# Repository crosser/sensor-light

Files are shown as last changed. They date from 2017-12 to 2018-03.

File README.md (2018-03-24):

## LED strip light controller ##

The project is to drive night lighting of a staircase using PIR
motion sensors (two: for the top and bottom of the staircase).
Ambient light sensor to only turn the LED chain when it is dark.
Driven by MSP430 MCU, light power controlled via PWM + MOSFET.



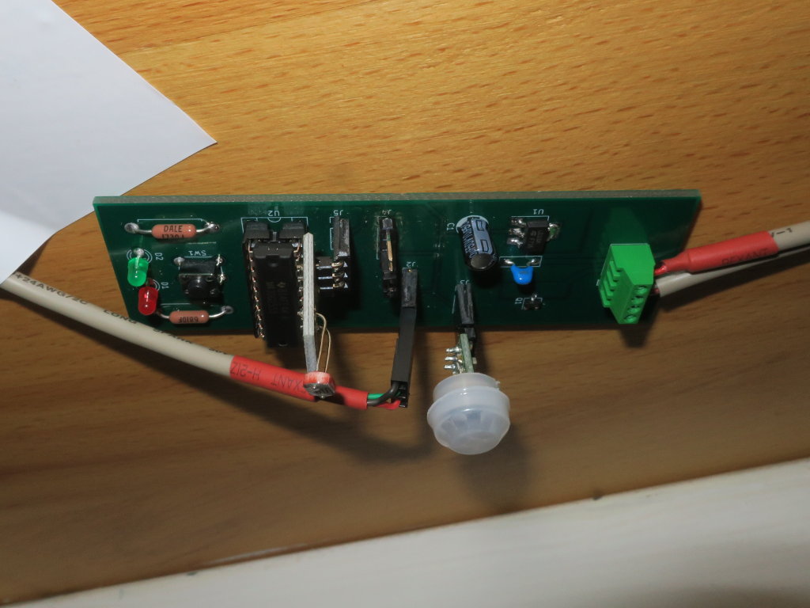
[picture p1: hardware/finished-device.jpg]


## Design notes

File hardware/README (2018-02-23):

Using this suggestion from electronics stackexchange:

https://electronics.stackexchange.com/questions/67775/driving-led-strip-from-microcontroller

MOSFET datasheet:

https://www.infineon.com/dgdl/irlml2502.pdf?fileId=5546d462533600a401535667f44d2602

MCU Power supply datasheet:

https://www.sparkfun.com/datasheets/Components/LD1117V33.pdf

Possible alternative MOSFET:

https://assets.nexperia.com/documents/data-sheet/PMV20XNE.pdf

Other parts:
Power regulator for MCU: TLV76033DBZT (TI, SOT-23-3, 100mA)
Schottky Diode power in: 757-1SS404H3F (Toschiba, SOT-323-3, 300mA, 0.38V drop)
			 PMEG6020ER (Nexperia, SOD123W, 2A, .5V drop)

Resistors for LEDs:
Red: 470
Green: 390 (270)

LEDs: TLLR4400, TLLG4400 Vishay Semiconductors
Vf=1.9V
If=2mA

Connector: AKZ692/4
https://www.ptr.eu/no_cache/en/produkte/produkt-pdf-generator/?cat_id=355

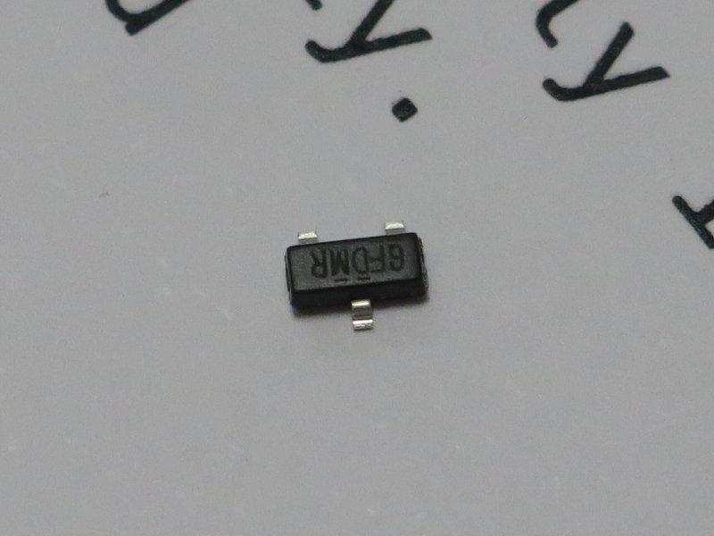
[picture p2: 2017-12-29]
hardware/IRLML2502.jpg

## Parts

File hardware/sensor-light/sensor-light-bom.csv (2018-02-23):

Id | Designator | Package | Quantity | Designation | Supplier and ref
1 | U1 | SOT-223 | 1 | Reg 3.3V
2 | C1 | CP_Radial_D5.0mm_P2.50mm | 1 | 10μF
3 | D1 | LED_D3.0mm | 1 | Red
4 | D2 | LED_D3.0mm | 1 | Green
5 | J2 | Socket_Strip_Straight_1x03_Pitch2.54mm | 1 | PIR Sensor 2
6 | J3 | Socket_Strip_Straight_1x03_Pitch2.54mm | 1 | PIR Sensor 1
7 | J4 | Socket_Strip_Straight_1x04_Pitch2.54mm | 1 | PROG Header
8 | J5 | Socket_Strip_Straight_1x03_Pitch2.54mm | 1 | Light Sensor
9 | J6 | AK300-4 | 1 | Power IN/OUT 12V
10 | Q1 | SOT-23_Handsoldering | 1 | IRLML2502
11 | R3 | R_Axial_DIN0411_L9.9mm_D3.6mm_P12.70mm_Horizontal | 1 | 47
12 | R4 | R_Axial_DIN0411_L9.9mm_D3.6mm_P12.70mm_Horizontal | 1 | 27
13 | SW1 | SW_PUSH_6mm_h5mm | 1 | Manual ON/OFF
14 | U2 | DIP-20_W7.62mm_Socket | 1 | MSP430G2553IN20
15 | C2 | C_Rect_L7.0mm_W2.5mm_P5.00mm | 1 | 100nF

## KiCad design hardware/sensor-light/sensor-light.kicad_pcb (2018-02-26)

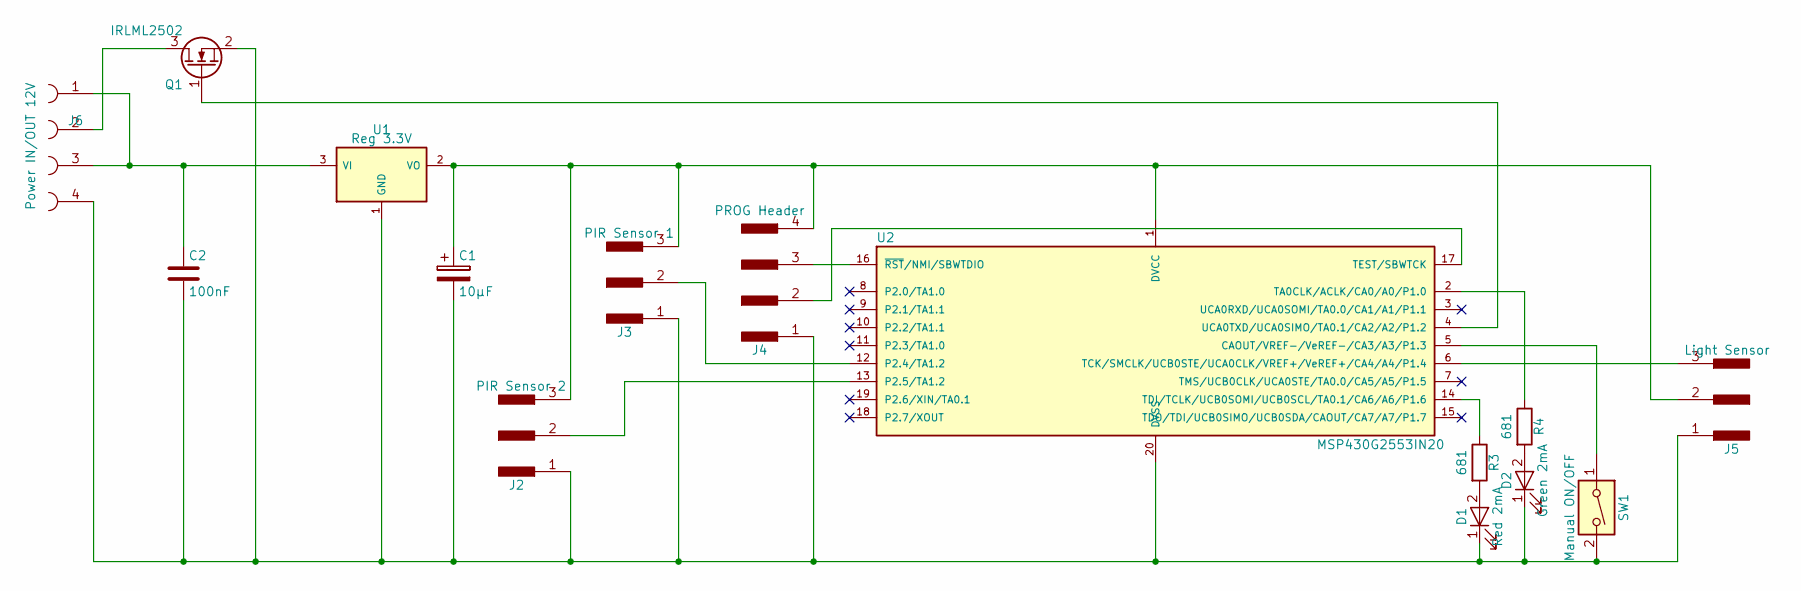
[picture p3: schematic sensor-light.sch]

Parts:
C1: 10μF; CP_Radial_D5.0mm_P2.50mm
C2: 100nF; C_Rect_L7.0mm_W2.5mm_P5.00mm
D1: Red 2mA; LED_D3.0mm
D2: Green 2mA; LED_D3.0mm
J2: PIR Sensor 2; Socket_Strip_Straight_1x03_Pitch2.54mm
J3: PIR Sensor 1; Socket_Strip_Straight_1x03_Pitch2.54mm
J4: PROG Header; Socket_Strip_Straight_1x04_Pitch2.54mm
J5: Light Sensor; Socket_Strip_Straight_1x03_Pitch2.54mm
J6: Power IN/OUT 12V; AKZ692_4
Q1: IRLML2502; SOT-23_Handsoldering
R3, R4: 681; R_Axial_DIN0411_L9.9mm_D3.6mm_P12.70mm_Horizontal
SW1: Manual ON/OFF; SW_PUSH_6mm_h5mm
U1: Reg 3.3V; SOT-223
U2: MSP430G2553IN20; DIP-20_W7.62mm_Socket

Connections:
unnamed: C1.1, J2.3, J3.3, J4.4, J5.2, U1.2 (VO), U2.1 (DVCC)
unnamed: C1.2, C2.2, D1.1 (K), D2.1 (K), J2.1, J3.1, J4.1, J5.1, J6.4, Q1.2 (S), SW1.2, U1.1 (GND), U2.20 (DVSS)
unnamed: C2.1, J6.1, J6.3, U1.3 (VI)
unnamed: D1.2 (A), R3.2
unnamed: D2.2 (A), R4.2
unnamed: J2.2, U2.13 (P2.5/TA1.2)
unnamed: J3.2, U2.12 (P2.4/TA1.2)
unnamed: J4.2, U2.17 (TEST/SBWTCK)
unnamed: J4.3, U2.16 (~RST~/NMI/SBWTDIO)
unnamed: J5.3, U2.6 (TCK/SMCLK/UCB0STE/UCA0CLK/VREF+/VeREF+/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)
unnamed: J6.2, Q1.3 (D)
unnamed: Q1.1 (G), U2.4 (UCA0TXD/UCA0SIMO/TA0.1/CA2/A2/P1.2)
unnamed: R3.1, U2.14 (TDI/TCLK/UCB0SOMI/UCB0SCL/TA0.1/CA6/A6/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)
unnamed: R4.1, U2.2 (TA0CLK/ACLK/CA0/A0/P1.0)
unnamed: SW1.1, U2.5 (CAOUT/VREF-/VeREF-/CA3/A3/P1.3)

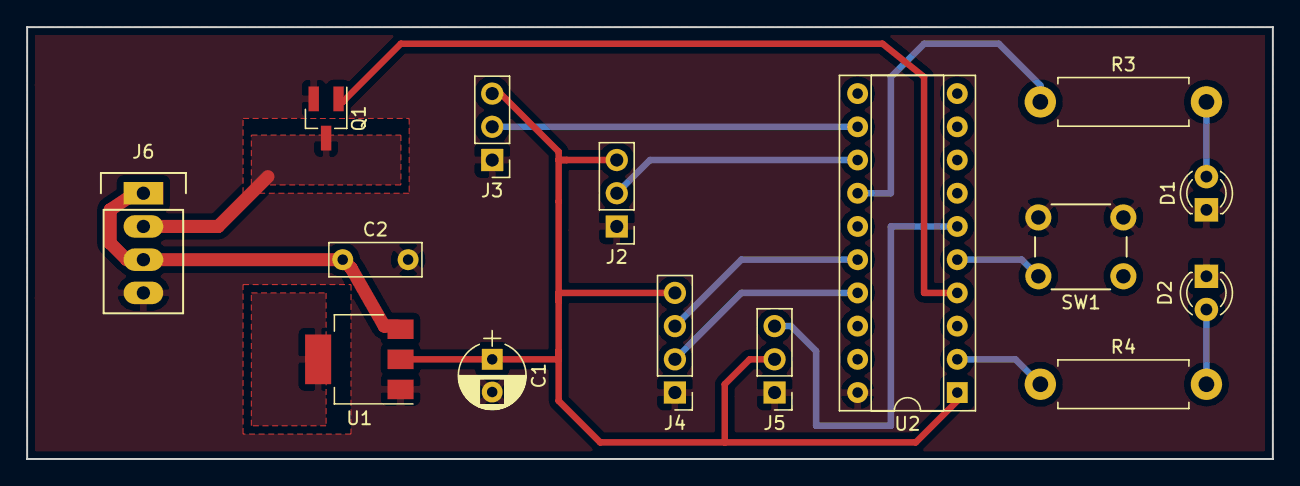
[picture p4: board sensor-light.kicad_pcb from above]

Board: 2 copper layers, 95.2 x 33.0 mm, 15 parts (0 on the bottom side), 15 nets.

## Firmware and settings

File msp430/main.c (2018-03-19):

#include <msp430.h> 

static volatile unsigned int ADC_Result;
static volatile unsigned int irq_events = 0;
enum {ev_btn1 = 0, ev_btn2, ev_pir1, ev_pir2, ev_tmr, ev_adc, ev_MAX};

#define PWM_ORDER 10
#define PWM_HALF 5
#define LIGHT_THRESHOLD 900
#define TIME_ON 320
	
#ifdef ADCSC /* Let us hope that this is a "new" model */
# define BIT_RL BIT0
# define BIT_GL BIT1
# define PBTN(x) P2##x
# define BIT_BTN BIT3
# define HAVE_BTN2
# define BIT_BTN2 BIT7
#else
# define BIT_RL BIT0
# define BIT_GL BIT6
# define PBTN(x) P1##x
# define BIT_BTN BIT3
# define BIT_BTN2 0
#endif

static int expon2(int duty)
{
	int shift = duty>>1;
	int comp = 1<<shift;
	int extra = (duty & 1) ? comp>>1 : 0;
	return (duty ? comp|extra : 0);
}

int main(void)
{
	int Duty_Cycle = 0;
	int Increment = 1;
	unsigned int Time_Left = 50;
	unsigned int Time_Indicate = 2;

	WDTCTL = WDTPW | WDTHOLD;	// stop watchdog timer
	// Configure GPIO Out
	P1DIR |= BIT_RL|BIT_GL|BIT2;	// Set LEDs & PWM to output direction
	P1OUT &= ~(BIT_RL|BIT_GL);	// LEDs off
#ifdef P1SEL1
	P1SEL1 |= BIT2;			// PWM out
#else
	P1SEL |= BIT2;			// PWM out
#endif

	// Configure GPIO In
	PBTN(DIR) &= ~(BIT_BTN|BIT_BTN2);	// Buttons
	PBTN(OUT) |= BIT_BTN|BIT_BTN2;		// Pull up
	PBTN(REN) |= BIT_BTN|BIT_BTN2;		// Enable pull-up
	PBTN(IES) |= BIT_BTN|BIT_BTN2;		// INT on Hi->Lo edge
	PBTN(IE)  |= BIT_BTN|BIT_BTN2;		// INT enable

	P2DIR &= ~(BIT4|BIT5);		// PIR Sensors
	P2OUT &= ~(BIT4|BIT5);		// Pull down
	P2REN &= ~(BIT4|BIT5);		// Disable pull
	P2IES &= ~(BIT4|BIT5);		// INT on Lo->Hi edge
	P2IE  |= BIT4|BIT5;		// INT enable

	// Configure ADC10

#ifdef ADCPCTL4 /* Newer model */
	SYSCFG2 |= ADCPCTL4|ADCPCTL5;	// disconnect pin 4 and 5 from GPIO
	ADCCTL0 |= ADCSHT_2 | ADCON;	// ADCON, S&H=16 ADC clks
	ADCCTL1 |= ADCSHP;		// ADCCLK = MODOSC; sampling timer
	ADCCTL2 |= ADCRES;		// 10-bit conversion results
	ADCMCTL0 |= ADCINCH_4;		// A4 ADC input select; Vref=AVCC
	ADCIE |= ADCIE0;		// Enable ADC conv complete interrupt
	// channel 5 is unused, reserved for measuring current
#else
	ADC10CTL0 = ADC10SHT_2 + ADC10ON + ADC10IE; // ADCON, S&H=16 ADC clks
	ADC10CTL1 = INCH_4;		// A4 ADC input select
	// channel 5 is unused, reserved for measuring current
#endif

	// Timer and PWM

#ifndef TASSEL__SMCLK
# define TASSEL__SMCLK TASSEL_2
# define MC__UP MC_1
# define MC__CONTINUOUS MC_2
# define TA0CCR2 TA0CCR1
# define TA0CCTL2 TA0CCTL1
#endif

	// Configure timer A0 for PWM
	TA0CCR0 = 1 << PWM_ORDER;	// PWM Period 2^10 ca. 1 kHz
	TA0CCR2 = 0;			// CCR1 PWM duty cycle
	TA0CCTL2 = OUTMOD_7;		// CCR1 reset/set
	TA0CTL = TASSEL__SMCLK | MC__UP | TACLR;// SMCLK, up mode
		// SMCLK, no divider, up mode, no interrupt, clear TAR

	//Configure timer A1 for counting time
	TA1CTL |= TASSEL__SMCLK | MC__CONTINUOUS | TACLR | TAIE;
		// SMCLK, no divider, continuous mode, interrupt enable

#ifdef LOCKLPM5
	// Disable the GPIO power-on default high-impedance mode to activate
	// previously configured port settings
	PM5CTL0 &= ~LOCKLPM5;
#endif

	while(1)
	{
		unsigned int events;

		_disable_interrupts();
		events = irq_events;
		irq_events = 0;
		_enable_interrupts();

		// Button 2 or PIR events initiate light measurement
		// and tuns on green or red led
		if (events & (1<<ev_btn2|1<<ev_pir1|1<<ev_pir2)) {
			if (events & 1<<ev_pir1)
				P1OUT |= BIT_GL;	// Set green LED on
			if (events & 1<<ev_pir2)
				P1OUT |= BIT_RL;	// Set red LED on
			// Sampling and conversion start
#ifdef ADCENC
			ADCCTL0 |= ADCENC | ADCSC;
#else
			ADC10CTL0 |= ENC + ADC10SC;
#endif
		}

		// End of light measurement. Set new Duty_Cycle,
		// zero increment and turn off green led
		if (events & 1<<ev_adc) {
			P1OUT ^= (BIT_GL|BIT_RL); // Flip green and red LEDs
			Time_Indicate = 5;
			if (ADC_Result < LIGHT_THRESHOLD)
				continue;
			Time_Left = TIME_ON;
			Increment = 1;
		}

		// Button 1 sets non-zero increment (and toggles it)
		if (events & 1<<ev_btn1) {
			P1OUT |= (BIT_GL|BIT_RL); // Set green and red LEDs on
			Time_Indicate = 5;
			if (Duty_Cycle > PWM_HALF) {
				Time_Left = 0;
				Increment = -1;
			} else {
				Time_Left = TIME_ON;
				Increment = 1;
			}
		}

		// Timer event (100 ms) changed duty cycle and flashes red led
		if (events & 1<<ev_tmr) {
			if (Time_Indicate) {
				Time_Indicate--;
				if (!Time_Indicate)
					P1OUT &= ~(BIT_RL|BIT_GL); // LEDs off
			}
			if (Time_Left) {
				Time_Left--;
				if (!Time_Left)
					if (Duty_Cycle)
						Increment = -1;
			}
			if (Increment > 0) {
				if (++Duty_Cycle >= (PWM_ORDER<<1)) {
					Duty_Cycle = PWM_ORDER<<1;
					Increment = 0;
				}
			} else if (Increment < 0) {
				if (--Duty_Cycle < 1) {
					Duty_Cycle = 0;
					Increment = 0;
				}
			} else // Increment _was_ zero - no change!
				continue;

			TA0CCR2 = expon2(Duty_Cycle);
		}
		__bis_SR_register(LPM0_bits | GIE);
		__no_operation();
	}
	return 0; /* not reached */
}

// TIMER interrupt routine
#if defined(__TI_COMPILER_VERSION__) || defined(__IAR_SYSTEMS_ICC__)
#pragma vector = TIMER1_A1_VECTOR
__interrupt void Timer_A (void)
#elif defined(__GNUC__)
void __attribute__ ((interrupt(TIMER1_A1_VECTOR))) Timer_A (void)
#else
#error Compiler not supported!
#endif
{
	switch(__even_in_range(TA1IV,TA1IV_TAIFG))
	{
		case TA1IV_NONE:
			break;	// No interrupt
		case TA1IV_TACCR1:
			break;	// CCR1 not used
		case TA1IV_TACCR2:
			break;	// CCR2 not used
		case TA1IV_TAIFG:
			irq_events |= 1<<ev_tmr;
			__bic_SR_register_on_exit(LPM0_bits);	// Wake up
			break;
		default:
			break;
	}
}

#ifndef ADC_VECTOR
# define ADCMEM0 ADC10MEM
# define ADC_VECTOR ADC10_VECTOR
#endif

// ADC interrupt service routine
#if defined(__TI_COMPILER_VERSION__) || defined(__IAR_SYSTEMS_ICC__)
#pragma vector=ADC_VECTOR
__interrupt void ADC_ISR(void)
#elif defined(__GNUC__)
void __attribute__ ((interrupt(ADC_VECTOR))) ADC_ISR (void)
#else
#error Compiler not supported!
#endif
{
#ifdef ADCIV_NONE
	switch(__even_in_range(ADCIV,ADCIV_ADCIFG))
	{
		case ADCIV_NONE:
			break;
		case ADCIV_ADCOVIFG:
			break;
		case ADCIV_ADCTOVIFG:
			break;
		case ADCIV_ADCHIIFG:
			break;
		case ADCIV_ADCLOIFG:
			break;
		case ADCIV_ADCINIFG:
			break;
		case ADCIV_ADCIFG:
#endif
			ADC_Result = ADCMEM0;
			irq_events |= 1<<ev_adc;
			__bic_SR_register_on_exit(LPM0_bits);	// Wake up
#ifdef ADCIV_NONE
			break;
		default:
			break;
	}
#endif
}

// GPIO interrupt service routine
#if defined(__TI_COMPILER_VERSION__) || defined(__IAR_SYSTEMS_ICC__)
#pragma vector=PORT2_VECTOR
__interrupt void Port_2(void)
#elif defined(__GNUC__)
void __attribute__ ((interrupt(PORT2_VECTOR))) Port_2 (void)
#else
#error Compiler not supported!
#endif
{
	if (P2IFG & BIT4) {
		irq_events |= 1<<ev_pir1;
		P2IFG &= ~BIT4;	// Clear P2.4 IFG
	}
	if (P2IFG & BIT5) {
		irq_events |= 1<<ev_pir2;
		P2IFG &= ~BIT5;	// Clear P2.5 IFG
	}
#if (PBTN() == P1)
	__bic_SR_register_on_exit(LPM0_bits);	// Wake up
}
// GPIO interrupt service routine
#if defined(__TI_COMPILER_VERSION__) || defined(__IAR_SYSTEMS_ICC__)
#pragma vector=PORT1_VECTOR
__interrupt void Port_1(void)
#elif defined(__GNUC__)
void __attribute__ ((interrupt(PORT1_VECTOR))) Port_1 (void)
#else
#error Compiler not supported!
#endif
{
#endif /* (PBTN() == P1) */
	if (PBTN(IFG) & BIT_BTN) {
		irq_events |= 1<<ev_btn1;
		PBTN(IFG) &= ~BIT_BTN;	// Clear button IFG
	}
#ifdef HAVE_BTN2
	if (PBTN(IFG) & BIT_BTN2) {
		irq_events |= 1<<ev_btn2;
		PBTN(IFG) &= ~BIT_BTN2;	// Clear button 2 IFG
	}
#endif
	__bic_SR_register_on_exit(LPM0_bits);	// Wake up
}

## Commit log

2017-12-13 parametrize button interrupts per model
2017-12-13 make PWM work on G2
2017-12-14 add initial schematics
    [schematic.sch]
2017-12-29 add picture of the MOSFET
2018-01-01 Make some electrical schematic with KiCad
    [sensor-light.kicad_pcb, sensor-light.sch]
2018-01-01 change pin flags to make ERC happy
    [sensor-light.sch]
2018-01-01 change lables on the schematic
    [sensor-light.sch]
2018-01-01 remove experimental schematics
    [schematic.sch]
2018-01-01 remove extra line on the schematics
    [sensor-light.sch]
2018-01-01 first attempt to assign footprints and make a pcb
    [sensor-light.kicad_pcb, sensor-light.sch]
2018-01-01 forgot the pcb file
2018-01-01 mention alternative MOSFET model
2018-01-02 make LED indication more meaningful
2018-01-02 make PWM duty cycle change more smoothly
2018-01-03 add resistors to the indicator LEDs
    [sensor-light.sch]
2018-02-10 attempt to place components on the PCB
    [sensor-light.kicad_pcb, sensor-light.sch]
2018-02-13 some attempt of pcb routing
    [sensor-light.kicad_pcb, sensor-light.sch]
2018-02-16 LED resistor values
2018-02-19 correct MOSFET pinout
    [sensor-light.sch]
2018-02-19 Attempt at laying out the board
    [sensor-light.kicad_pcb, sensor-light.sch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]
2018-02-20 try adust layout
    [sensor-light.kicad_pcb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]
2018-02-20 save unsaved
    [sensor-light.kicad_pcb]
2018-02-20 they are called geRber, right?
    [sensor-light-B.Cu.gbr, sensor-light-B.SilkS.gbr, sensor-light-F.Cu.gbr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]
2018-02-20 add capacitor to the regulator input
    [sensor-light.sch]
2018-02-21 layout adjustments
    [sensor-light.kicad_pcb, sensor-light.sch]
2018-02-21 some fiddling with thermal releif areas
    [sensor-light.kicad_pcb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]
2018-02-21 rebuild picture of the schematics
2018-02-21 redraw board, with correct releif areas
    [sensor-light.kicad_pcb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]
2018-02-22 minor adjustment in traces and labels
    [sensor-light.kicad_pcb, sensor-light.sch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]
2018-02-23 play with BOM creation
    [sensor-light-bom.csv]
2018-02-23 Change the power connector type
    because I could not order AK300 :-\
    [sensor-light.kicad_pcb, sensor-light.sch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]
2018-02-26 export missing gerber files
    [sensor-light.kicad_pcb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]
2018-03-19 disable pull up/down - PIR signal too weak
    [main.c]
2018-03-24 Add picture of the finished device
